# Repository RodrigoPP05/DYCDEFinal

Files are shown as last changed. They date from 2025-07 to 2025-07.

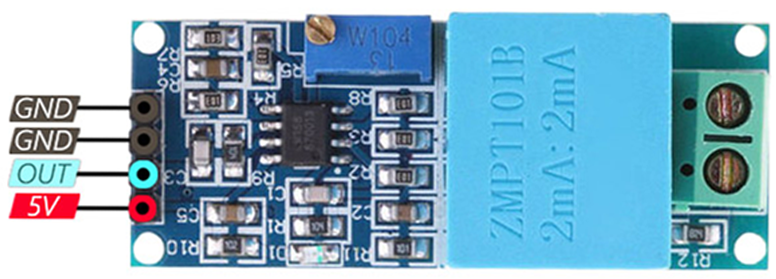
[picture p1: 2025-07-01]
Proyecto/Imagenes/ZMPT101-B-Voltage-Sensor-Pinout.png

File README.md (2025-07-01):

# 🌱 Smart Air and Soil Monitor - Proyecto Final DYCDE 2025

Este proyecto tiene como objetivo principal monitorear y automatizar el ambiente en invernaderos y sistemas hidropónicos a pequeña escala mediante una solución IoT. Se integra con sensores para medir temperatura, humedad, presión, calidad del aire y humedad del suelo, así como actuadores como bombas y ventiladores, todo gestionado desde un ESP32.

Los datos se visualizan en tiempo real desde cualquier dispositivo móvil mediante una interfaz web creada en Node-RED, y se transmiten usando MQTT con notificaciones vía Telegram.

- Temperatura y humedad ambiental (BME680)
- Humedad del suelo (sensor capacitivo)
- Concentración de gases (BME680)
- Nivel de agua (flotador)
- Tensión de alimentación (ZMPT101B)

Además, controla automáticamente una bomba, ventilador y lámpara LED mediante relés. Los datos son publicados vía MQTT y pueden visualizarse en dashboards interactivos de Node-RED. También se envían alertas al usuario mediante Telegram.

---

## ⚙️ Tecnologías y herramientas utilizadas

- **ESP32** como unidad principal de procesamiento.
- **Arduino IDE** para la programación del firmware.
- **Altium Designer** para el diseño esquemático y de la PCB.
- **Node-RED** como interfaz de control y visualización.
- **TinkerCAD** para el diseño 3D de la carcasa.
- **Mosquitto MQTT** para la comunicación de datos entre nodos.

---

## 📂 Contenido del repositorio

| Archivo/Carpeta | Descripción |
|---|---|
| `Proyecto/` | Carpeta con archivos base del proyecto, como esquemáticos en Altium. |
| `Presentación_de_Proyecto_DYCDE_2025.pdf` | Informe final en PDF que documenta todo el proyecto. |
| `Proyecto.DXF` | Modelo 2D del diseño de la carcasa/exportado desde TinkerCAD o Altium. |
| `Proyecto.step` | Modelo 3D completo del sistema (incluye PCB y carcasa). |
| `Proyectofinal.ino` | Código para ESP32 (firmware compatible con Arduino IDE). |
| `README.md` | Archivo de descripción general del repositorio (este mismo documento). |

---

## 📷 Capturas del sistema

- Interfaz en Node-RED con flujos de sensores, controladores y Telegram.
- Visualización de sensores (temperatura, humedad, suelo) desde el dashboard.
- Publicaciones MQTT en tiempo real desde Mosquitto.
- Diseño en 3D de la carcasa impresa y la PCB.

---

## 🔗 Cómo ejecutar

1. Abre `Proyectofinal.ino` en Arduino IDE y cárgalo al ESP32.
2. En Node-RED, importa el flujo (opcional).
3. Asegúrate de tener Mosquitto instalado como broker MQTT.
4. Configura WiFi, tópicos y tokens de Telegram en el código.

---

## 📥 Requisitos

- Arduino IDE con librerías: `Adafruit_BME680`, `DallasTemperature`, `OneWire`, `PubSubClient`, `UniversalTelegramBot`.
- Node-RED instalado en PC o Raspberry Pi.
- Mosquitto broker funcionando localmente o en la nube.
- Acceso a red WiFi.
- Cuenta de Telegram y creación de un bot con token.
- ESP32 DevKit v1 o equivalente
- Sensores: BME680, DS18B20, sensor de humedad capacitivo, ZMPT101B
- Módulo de relés (3 canales)
- Aplicación Telegram
---

## 📦 Descargas recomendadas

- [Arduino IDE](https://www.arduino.cc/en/software) – para cargar el firmware al ESP32
- [Altium Designer (versión de prueba)](https://www.altium.com/altium-designer/free-trial) – para editar el diseño de la PCB
- [Node-RED](https://nodered.org/docs/getting-started/) – para visualizar dashboards y controlar actuadores
- [Mosquitto MQTT](https://mosquitto.org/download/) – broker MQTT para pruebas locales o en la nube

## 📱 Visualización remota

El sistema puede monitorearse desde cualquier dispositivo móvil a través de:
- Interfaz web de Node-RED
- Alertas en Telegram con botones de control integrados

## 📧 Contacto

**Rodrigo Ponce Paz**  
Estudiante de Ingeniería en Electrónica  
Universidad Galileo - FISICC  
GitHub: [@RodrigoPP05](https://github.com/RodrigoPP05)

---

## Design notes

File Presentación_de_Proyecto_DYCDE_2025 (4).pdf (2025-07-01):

Proyecto Final - DYCDE - 2025

# Smart Air and Soil Monitor

Rodrigo Ponce Paz - 23000642¹

1
Ingeniería en Electrónica - FISICC

July 1, 2025

## Abstract

Este proyecto aborda las dificultades que enfrentan pequeños productores y jardineros urbanos para mantener condiciones óptimas en invernaderos caseros y sistemas hidropónicos. El riego manual y el control ambiental requieren supervisión constante, lo que genera ineficiencias y riesgos como desperdicio de agua y estrés en las plantas. Para solucionarlo, se desarrolló un sistema IoT integrado que monitorea continuamente la humedad del sustrato, niveles de agua, temperatura, humedad y calidad del aire. El sistema controla automáticamente bombas, válvulas y ventiladores para optimizar la salud vegetal y el uso de recursos. Los datos son accesibles remotamente vía app móvil o interfaz web, con alertas en tiempo real y registros históricos. Las pruebas iniciales muestran mayor estabilidad en las condiciones de cultivo, ahorro de agua y menor riesgo de enfermedades.

Keywords: Electronics, IoT, Diseño y Construcción, Dispositivos Electrónicos

## 1 Descripción del problema

Muchos pequeños productores, aficionados a la jardinería y operadores de invernaderos caseros enfrentan dificultades para mantener condiciones óptimas de cultivo de manera constante. El riego manual y la ventilación oportuna dependen de la supervisión continua, lo cual:

- Consume tiempo y esfuerzo humano.
- Genera variabilidad en la humedad de suelo, temperatura y calidad del aire.
- Desperdicia recursos (agua, energía eléctrica) al activar bombas o ventiladores innecesariamente.

## 2 Objetivo General

Desarrollar un sistema IoT integrado que automatice y optimice el riego y el ambiente interno de invernaderos o cultivos hidropónicos a pequeña escala, mediante:

- Monitorización continua de humedad del sustrato, nivel de agua, temperatura, humedad ambiental y concentración de gases contaminantes.
- Control automático de bombas de riego, válvulas, ventiladores/extractores y, opcionalmente, iluminación de cultivo.
- Alertas y visualización remota vía Telegram o interfaz web (Wi-Fi/Bluetooth), para notificaciones en tiempo real y consulta de históricos.

## 3 Objetivos Específicos

## - Pequeños productores urbanos: Inver-

naderos caseros, huertos en azoteas o balcones, y sistemas hidropónicos domésticos.

## - Hobbyistas y entornos educativos: Es-

cuelas técnicas, laboratorios universitarios, makerspaces y talleres de agricultura urbana.

## - Microempresas de cultivo controlado:

Productores de plantas ornamentales, hierbas aromáticas, microverdes y germinados para mercados locales o restaurantes.

- Mantener controlado el nivel de humedad del sustrato en el cultivo, mediante la automatización del riego, para optimizar las condiciones que favorecen el crecimiento y florecimiento saludable de las plantas.

## 4 Materiales (BOM List)

En esta sección se presenta la lista de componentes y herramientas utilizados para la implementación del sistema de monitoreo y automatización IoT aplicado a invernaderos y entornos hidropónicos a pequeña escala.

- Microcontrolador ESP32 (Wi-Fi/Bluetooth)
- Sensor capacitivo de humedad del suelo
- Sensor DS18B20 (temperatura)
- Sensor BME680 (presión, humedad, temperatura)
- Módulo de relés de 3 canales
- Bomba de agua 12V, ventilador extractor, lámpara LED
- Sensor ZMPT101B (voltaje)
- Fuente de 5V DC + convertidores step-down
- Protoboard y cables jumper
- Aplicación móvil por Wi-Fi

## 5 Discusión

El sistema propuesto es técnicamente viable, económicamente accesible y fácilmente escalable. Representa una herramienta real para la mejora de cultivos urbanos e hidropónicos, reduciendo pérdidas, optimizando recursos y brindando acceso al monitoreo remoto, lo que lo convierte en una solución eficaz para ambientes domésticos, educativos y microempresariales.

## 6 Resultados

Table 1: Temperatura y humedad ambiental (últimas 2 semanas)
Fecha | Temp. (°C) | Humedad (%)
2025-06-17 2025-06-18 2025-06-19 2025-06-20 2025-06-21 2025-06-22 2025-06-23 2025-06-24 2025-06-25 2025-06-26 2025-06-27 2025-06-28 2025-06-29 2025-06-30 | 24.79 24.27 25.21 24.19 24.90 24.50 25.11 24.63 25.00 24.78 25.05 24.38 25.15 24.93 | 66.62 71.17 69.03 62.71 68.97 67.58 70.12 65.33 68.44 66.90 69.28 68.12 67.00 70.30

Table 2: Presión, gases y humedad del suelo (últimas 2 semanas)
Fecha | Presión (hPa) | Gas (k) | Suelo (%)
2025-06-17 2025-06-18 2025-06-19 2025-06-20 2025-06-21 2025-06-22 2025-06-23 2025-06-24 2025-06-25 2025-06-26 2025-06-27 2025-06-28 2025-06-29 2025-06-30 | 856.56 856.64 856.37 856.34 856.94 856.73 856.68 856.48 856.32 856.76 856.39 856.42 856.89 856.81 | 14.52 28.29 25.35 23.80 25.37 30.48 20.14 18.97 22.54 27.01 24.99 26.77 19.36 21.88 | 60 100 60 85 60 90 85 70 100 85 90 60 100 85

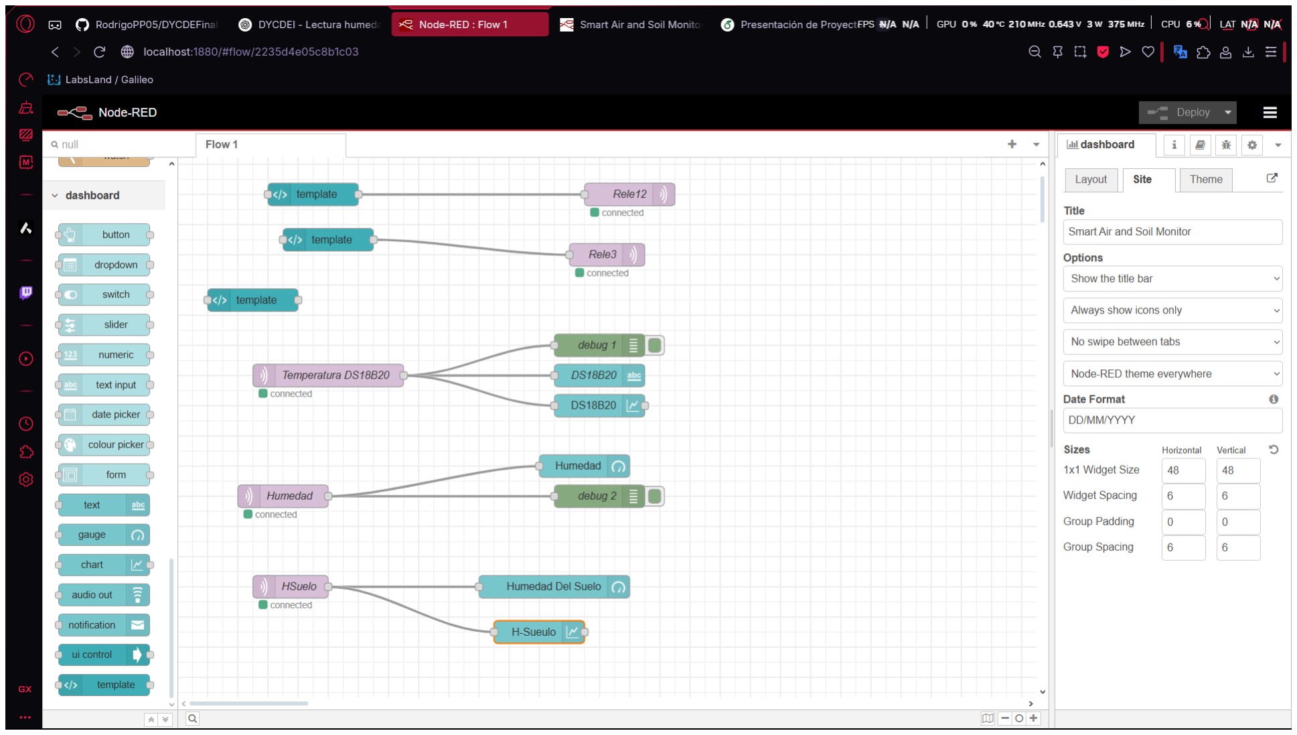
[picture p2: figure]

Figure 1: Interfaz en Node-RED mostrando el flujo lógico entre sensores, procesamiento y actuadores, incluyendo dashboards y conexión con Telegram.

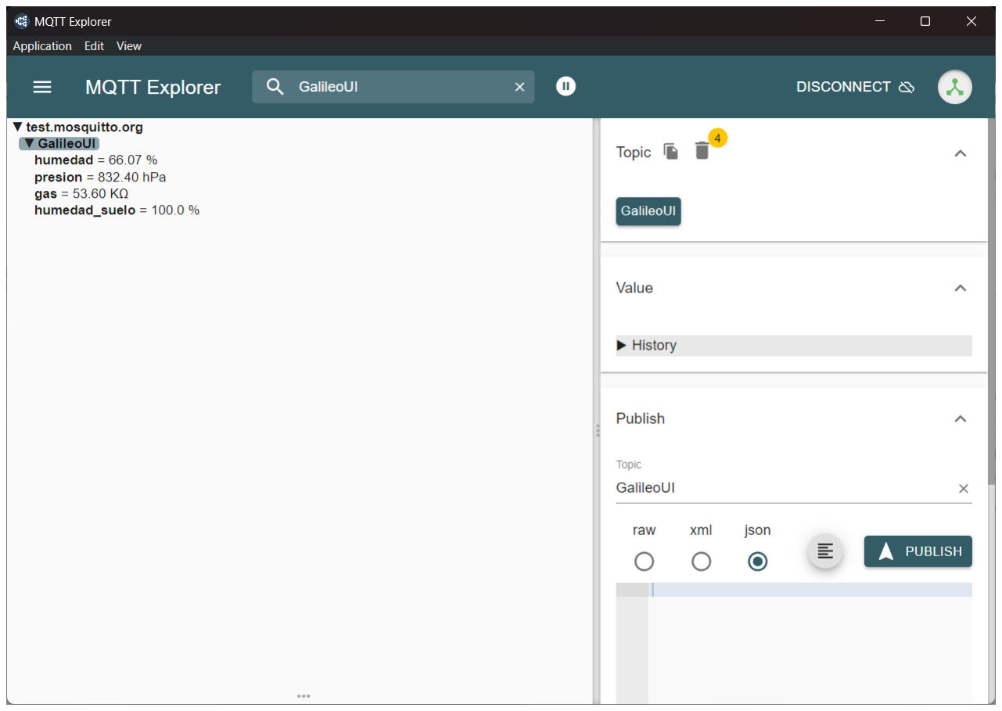
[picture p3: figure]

Figure 2: Monitoreo de datos en tiempo real usando MQTT a través del cliente Mosquitto, observando las publicaciones de tópicos.

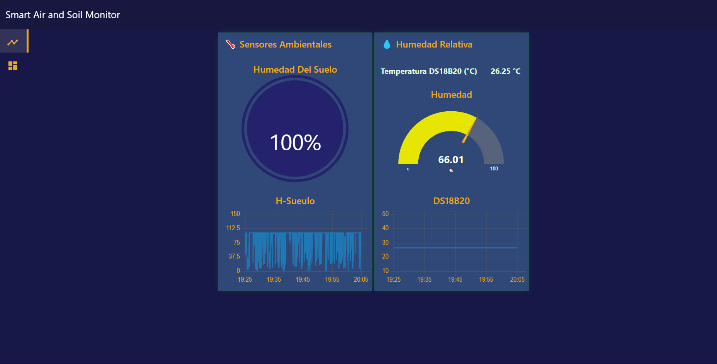
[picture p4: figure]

Figure 3: Visualización del dashboard desde un dispositivo móvil, demostrando accesibilidad remota a través de red local o internet.

## 7 Diseño del Sistema

El diseño del sistema incluye tanto la parte electrónica como la estructural. A continuación se presentan los principales elementos desarrollados durante la implementación del prototipo, desde el diseño del esquemático hasta la representación física de la carcasa.

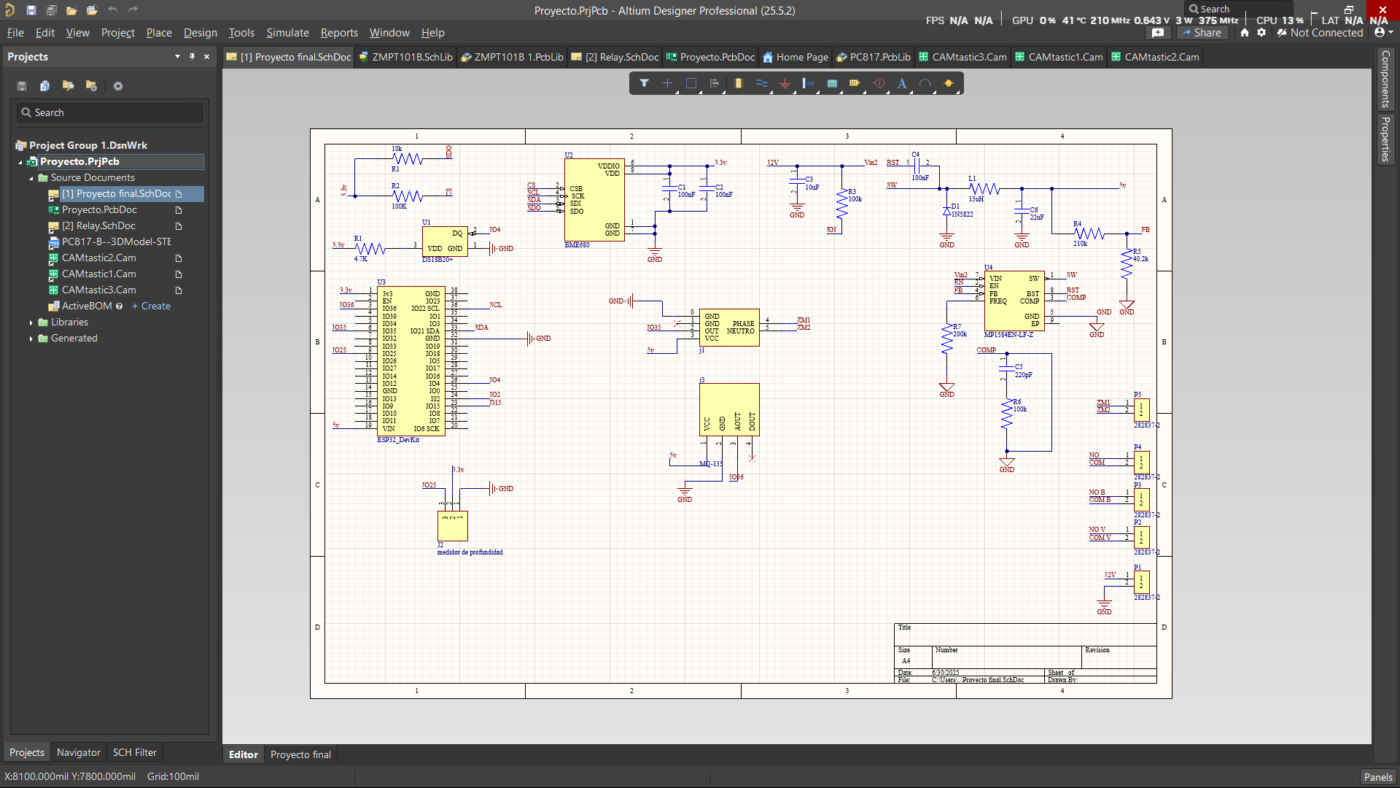
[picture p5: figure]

Figure 4: Esquemático del sistema completo desarrollado en Altium Designer.

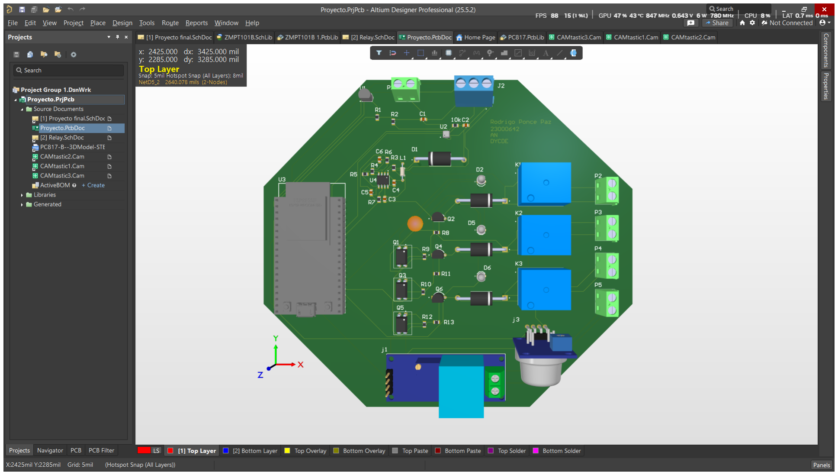
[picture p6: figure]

Figure 5: Vista tridimensional de la PCB, mostrando la disposición de componentes.

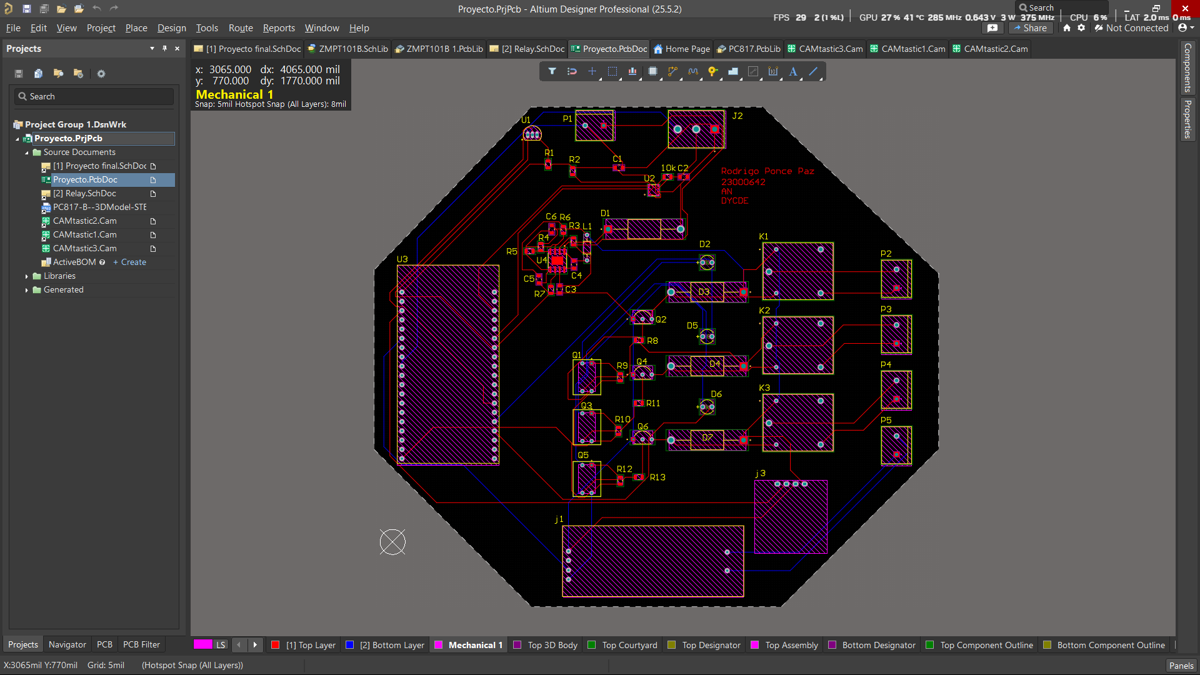
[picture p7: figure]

Figure 6: Vista 2D de la PCB, ilustrando el ruteo de pistas.

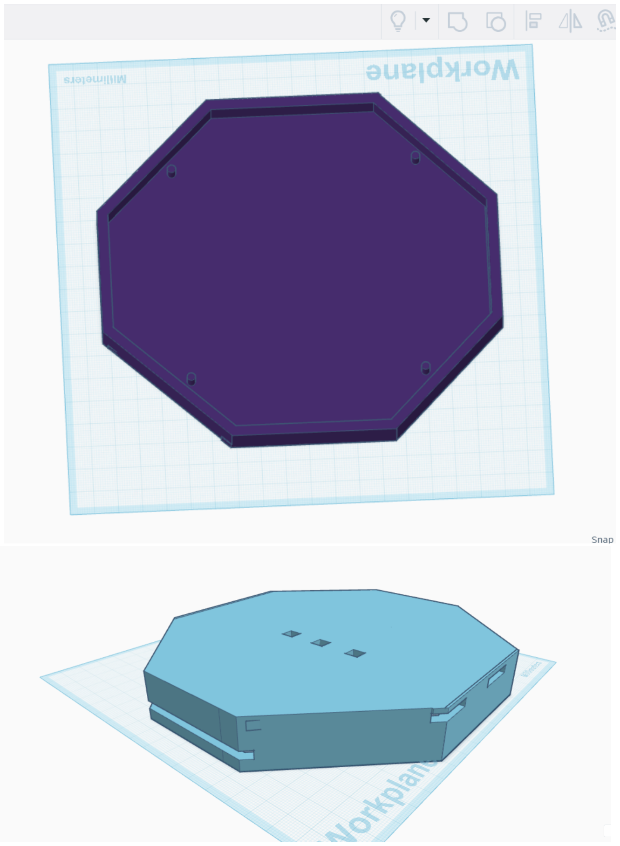
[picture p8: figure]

Figure 7: Carcasa personalizada diseñada en TinkerCAD para alojar el sistema.

## Conclusiones

El sistema desarrollado demostró ser una solución eficiente, funcional y accesible para el monitoreo y automatización de cultivos. A lo largo de las pruebas, se logró mantener estables las variables del entorno, optimizar el uso de recursos y brindar al usuario un sistema de supervisión remota y control automatizado.

El proyecto tiene potencial de aplicación práctica en ambientes educativos, urbanos y comerciales. Se recomienda como trabajo futuro la implementación de inteligencia artificial, energía solar y conexión a bases de datos para análisis predictivo.

## Agradecimientos

Agradezco a los docentes de la Universidad Galileo, así como a mi familia y compañeros de clase, cuyo apoyo fue fundamental en la planificación, implementación y validación de este proyecto.

## References

[1] Simon Monk, Programming Arduino: Getting Started with Sketches. McGraw-Hill Education, 2016.
[2] Espressif Systems, ESP32 Technical Reference Manual, Disponible en: https://www. espressif.com
[3] Peter H. Cuno, IoT Projects with ESP32. Packt Publishing, 2021.
[4] Pavia, D. L., Lampman, G. M., Kriz, G. S., & Engel, R. G. Introducción a la técnica y análisis orgánico. Cengage Learning, 2015.

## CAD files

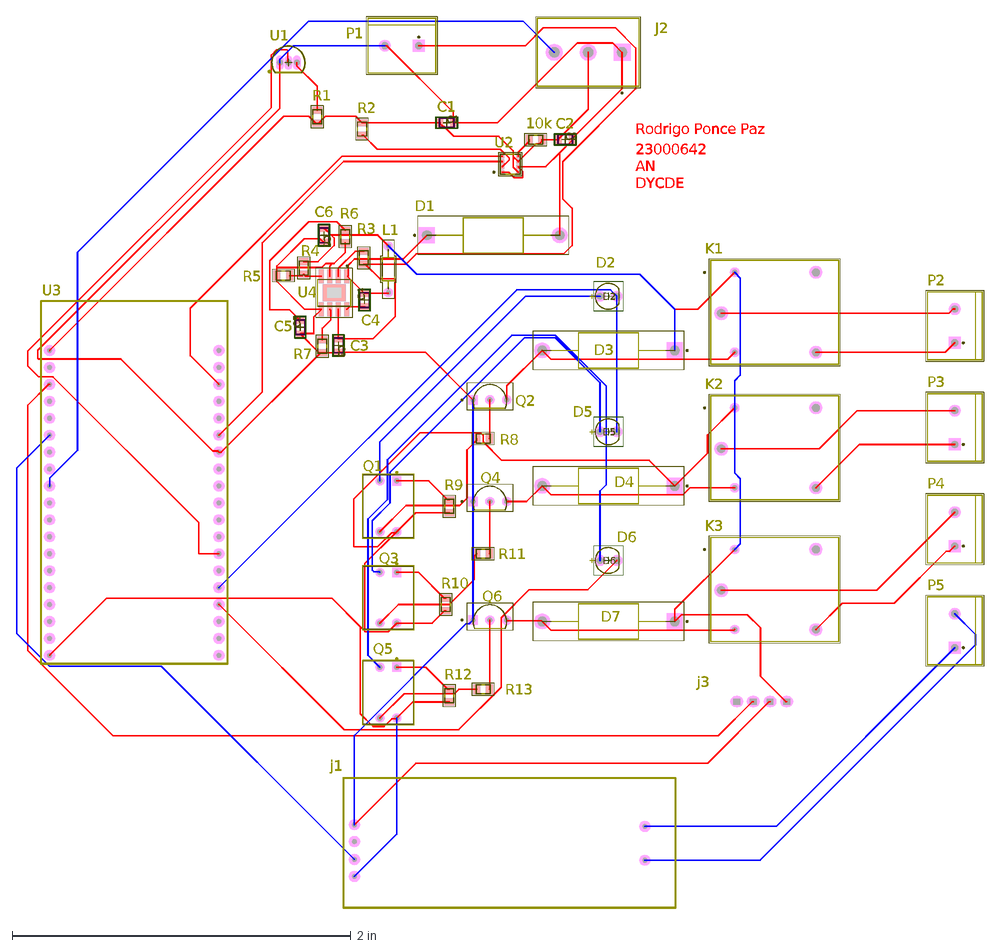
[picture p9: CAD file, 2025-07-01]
Proyecto.DXF
Rodrigo Ponce Paz
23000642
AN
DYCDE
j3
Q6
Q4
Q2
R1
j1
P5
J2
U4
U3
U2
U1
R13
R12
R11
R10
R9
R8
R7
R6
R5
R4
R3
R2
Q5
Q3
Q1
P4
P3
P2
P1
L1
K3
K2
K1
D1
D7
+
D6
D5
D4
D3
D2
C6
C5
C4
C3
C2
C1
10k

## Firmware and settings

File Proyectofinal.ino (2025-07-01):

#include <WiFi.h>
#include <PubSubClient.h>
#include <OneWire.h>
#include <DallasTemperature.h>
#include <Wire.h>
#include <Adafruit_Sensor.h>
#include "Adafruit_BME680.h"
#include <UniversalTelegramBot.h>
#include <WiFiClientSecure.h>

// Pines
#define ONE_WIRE_BUS 4
#define PIN_RELE 15
#define PIN_RELE12 2
#define PIN_HUMEDAD_SUELO 36

OneWire oneWire(ONE_WIRE_BUS);
DallasTemperature ds18b20(&oneWire);
Adafruit_BME680 bme;

// WiFi y MQTT
struct RedWiFi {
  const char* ssid;
  const char* password;
};

RedWiFi redesDisponibles[] = {
  {"Galaxy S10+eae2", "sbio0892"},
  {"TIGO-BB8F", "4G79ED802919"},
  {"CasaWifi", "claveCasa"},
  {"OtraRed", "claveOtra"}
};

const char* mqtt_server = "test.mosquitto.org";
WiFiClient espClient;
PubSubClient client(espClient);

// Telegram
const char* BOTtoken = "8119686924:AAEEjtBgANiSd2eGeN33igCYa2kWQp2HZMs";
const char* chat_id = "1776359286";
WiFiClientSecure secured_client;
UniversalTelegramBot bot(BOTtoken, secured_client);

// Estados
String ipESP32 = "";
bool alertaRiegoEnviada = false;

void mostrarBotones() {
  String keyboardJson =
    "[[{\"text\":\"📊 Estado\",\"callback_data\":\"estado\"},"
    "{\"text\":\"🔁 Reiniciar\",\"callback_data\":\"reiniciar\"}],"
    "[{\"text\":\"#3 ⚡\",\"callback_data\":\"encender_rele\"},"
    "{\"text\":\"#3 ❌\",\"callback_data\":\"apagar_rele\"}],"
    "[{\"text\":\"BL💡\",\"callback_data\":\"encender_rele12\"},"
    "{\"text\":\"BL ❌\",\"callback_data\":\"apagar_rele12\"}],"
    "[{\"text\":\"🌐 Ver Panel\",\"url\":\"http://" + ipESP32 + ":1880/ui\"}]]";

  bot.sendMessageWithInlineKeyboard(chat_id, "¿Qué deseas hacer?", "", keyboardJson);
}

void setup_wifi() {
  delay(100);
  Serial.println("🔍 Escaneando redes WiFi...");

  int cantidad = WiFi.scanNetworks();
  int mejorRSSI = -1000;
  const char* mejorSSID = nullptr;
  const char* mejorPass = nullptr;

  for (int i = 0; i < cantidad; i++) {
    String ssidDetectada = WiFi.SSID(i);
    int rssi = WiFi.RSSI(i);

    for (RedWiFi red : redesDisponibles) {
      if (ssidDetectada == red.ssid && rssi > mejorRSSI) {
        mejorRSSI = rssi;
        mejorSSID = red.ssid;
        mejorPass = red.password;
      }
    }
  }

  if (mejorSSID != nullptr) {
    Serial.printf("📶 Conectando a: %s (RSSI: %d)\n", mejorSSID, mejorRSSI);
    WiFi.begin(mejorSSID, mejorPass);

    while (WiFi.status() != WL_CONNECTED) {
      delay(500); Serial.print(".");
    }

    Serial.println("\n✅ Conectado a WiFi");
    ipESP32 = WiFi.localIP().toString();
    Serial.println("IP: " + ipESP32);

    secured_client.setInsecure();
    bot.sendMessage(chat_id, "☁️ ESP32 conectado a WiFi: " + String(mejorSSID), "");
    bot.sendMessage(chat_id, "🌐 IP local del ESP32: " + ipESP32, "");

    mostrarBotones();
    delay(1000);
    bot.getUpdates(bot.last_message_received + 1);
  } else {
    Serial.println("❌ Ninguna red conocida encontrada.");
  }
}

void reconnect() {
  while (!client.connected()) {
    Serial.print("Conectando a MQTT...");
    if (client.connect("ESP32SensorNode")) {
      Serial.println(" conectado.");
      client.subscribe("GalileoUI/rele");
      client.subscribe("GalileoUI/rele12");
    } else {
      Serial.print(" falló, rc="); Serial.println(client.state());
      delay(2000);
    }
  }
}

void callback(char* topic, byte* payload, unsigned int length) {
  String message;
  for (int i = 0; i < length; i++) message += (char)payload[i];

  if (String(topic) == "GalileoUI/rele")
    digitalWrite(PIN_RELE, message == "1" ? LOW : HIGH);

  if (String(topic) == "GalileoUI/rele12")
    digitalWrite(PIN_RELE12, message == "1" ? LOW : HIGH);
}

void enviarEstado(String id, float tempDS, float hum, float pres, float gas, float humSuelo) {
  String respuesta = "📡 Estado actual:\n";
  respuesta += "🌡️ DS18B20: " + String(tempDS, 2) + " °C\n";
  respuesta += "💧 Humedad: " + String(hum, 2) + " %\n";
  respuesta += "🧭 Presión: " + String(pres, 2) + " hPa\n";
  respuesta += "🫧 Gas: " + String(gas, 2) + " KΩ\n";
  respuesta += "🌱 Suelo: " + String(humSuelo, 1) + " %";
  bot.sendMessage(id, respuesta, "");
}

void setup() {
  Serial.begin(115200);
  pinMode(PIN_RELE, OUTPUT); digitalWrite(PIN_RELE, HIGH);
  pinMode(PIN_RELE12, OUTPUT); digitalWrite(PIN_RELE12, HIGH);
  pinMode(PIN_HUMEDAD_SUELO, INPUT);

  setup_wifi();
  client.setServer(mqtt_server, 1883);
  client.setCallback(callback);
  ds18b20.begin();

  if (!bme.begin()) {
    bot.sendMessage(chat_id, "❌ No se detectó el BME680.", "");
    while (1);
  }

  bme.setTemperatureOversampling(BME680_OS_8X);
  bme.setHumidityOversampling(BME680_OS_2X);
  bme.setPressureOversampling(BME680_OS_4X);
  bme.setGasHeater(320, 150);
}

void loop() {
  if (!client.connected()) reconnect();
  client.loop();

  ds18b20.requestTemperatures();
  float tempDS = ds18b20.getTempCByIndex(0);
  if (tempDS == 85.0 || tempDS == DEVICE_DISCONNECTED_C)
    bot.sendMessage(chat_id, "⚠️ DS18B20 no responde", "");

  if (!bme.performReading()) return;

  float hum = bme.humidity;
  float pres = bme.pressure / 100.0;
  float gas = bme.gas_resistance / 1000.0;

  int valorCrudo = analogRead(PIN_HUMEDAD_SUELO);
  float humedadSuelo = map(valorCrudo, 2996, 1180, 0, 100);
  humedadSuelo = constrain(humedadSuelo, 0, 100);
  Serial.printf("🌱 Suelo crudo: %d | Humedad: %.1f %%\n", valorCrudo, humedadSuelo);

  // Activación automática del riego
//  if (humedadSuelo < 50.0) {
//    digitalWrite(PIN_RELE12, LOW);
//    if (!alertaRiegoEnviada) {
//      bot.sendMessage(chat_id, "🚨 Humedad baja: " + String(humedadSuelo, 1) + " %. Activando bomba y LED.", "");
//      alertaRiegoEnviada = true;
//    }
//  } else {
//    digitalWrite(PIN_RELE12, HIGH);
//    if (alertaRiegoEnviada) {
//      bot.sendMessage(chat_id, "✅ Humedad recuperada: " + String(humedadSuelo, 1) + " %. Bomba y LED apagados.", "");
//      alertaRiegoEnviada = false;
//    }
//  }

  // MQTT
  client.publish("GalileoUI/temp_DS18", (String(tempDS, 2) + " °C").c_str());
  client.publish("GalileoUI/humedad", (String(hum, 2) + " %").c_str());
  client.publish("GalileoUI/presion", (String(pres, 2) + " hPa").c_str());
  client.publish("GalileoUI/gas", (String(gas, 2) + " KΩ").c_str());
  client.publish("GalileoUI/humedad_suelo", (String(humedadSuelo, 1) + " %").c_str());

  // Telegram comandos
  int numMessages = bot.getUpdates(bot.last_message_received + 1);
  while (numMessages) {
    for (int i = 0; i < numMessages; i++) {
      String tipo = bot.messages[i].type;
      String texto = bot.messages[i].text;
      String chat = bot.messages[i].chat_id;
      String query_id = bot.messages[i].query_id;

      if (tipo == "message") {
        if (texto == "/estado" || texto == "📊 Estado")
          enviarEstado(chat, tempDS, hum, pres, gas, humedadSuelo);
        else if (texto == "/reiniciar" || texto == "🔁 Reiniciar") {
          bot.sendMessage(chat, "♻️ Reiniciando ESP32...", "");
          delay(1000); ESP.restart();
        }
      }

      if (tipo == "callback_query") {
        if (texto == "estado") {
          enviarEstado(chat, tempDS, hum, pres, gas, humedadSuelo);
          bot.answerCallbackQuery(query_id, "📊 Estado enviado");
        } else if (texto == "reiniciar") {
          bot.answerCallbackQuery(query_id, "♻️ Reiniciando...");
          bot.sendMessage(chat, "🔄 Reiniciando ESP32...", "");
          delay(1000); ESP.restart();
        } else if (texto == "encender_rele") {
          digitalWrite(PIN_RELE, LOW);
          bot.answerCallbackQuery(query_id, "⚡ Relé encendido");
        } else if (texto == "apagar_rele") {
          digitalWrite(PIN_RELE, HIGH);
          bot.answerCallbackQuery(query_id, "❌ Relé apagado");
        } else if (texto == "encender_rele12") {
          digitalWrite(PIN_RELE12, LOW);
          bot.answerCallbackQuery(query_id, "⚡ Relé12 encendido");
        } else if (texto == "apagar_rele12") {
          digitalWrite(PIN_RELE12, HIGH);
          bot.answerCallbackQuery(query_id, "❌ Relé12 apagado");
        }
      }
    }
    numMessages = bot.getUpdates(bot.last_message_received + 1);
  }

  delay(2000);
}

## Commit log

2025-07-01 Codigo ESP32.ino
2025-07-01 modelos 3D
    [Proyecto.DXF]
2025-07-01 📈 Actualizar datos sensor
2025-07-01 📈 Añadir nuevo registro
